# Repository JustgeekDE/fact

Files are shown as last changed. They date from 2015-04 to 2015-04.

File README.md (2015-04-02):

# Simple Fact
## Overview
Simple Fact (a simple **F**lash **a**nd **c**amera **t**rigger) is a smallish ([SoB 5x5](http://dangerousprototypes.com/docs/Sick_of_Beige_standard_PCB_sizes_v1.0)) tool to automatically trigger a a camera or camera flash based on sounds or light impulses.

The whole system is planned to be Arduino compatible to allow easy extension.

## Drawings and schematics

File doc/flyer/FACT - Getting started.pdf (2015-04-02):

## 1. 2. Connect in- and outputs Select the trigger mode

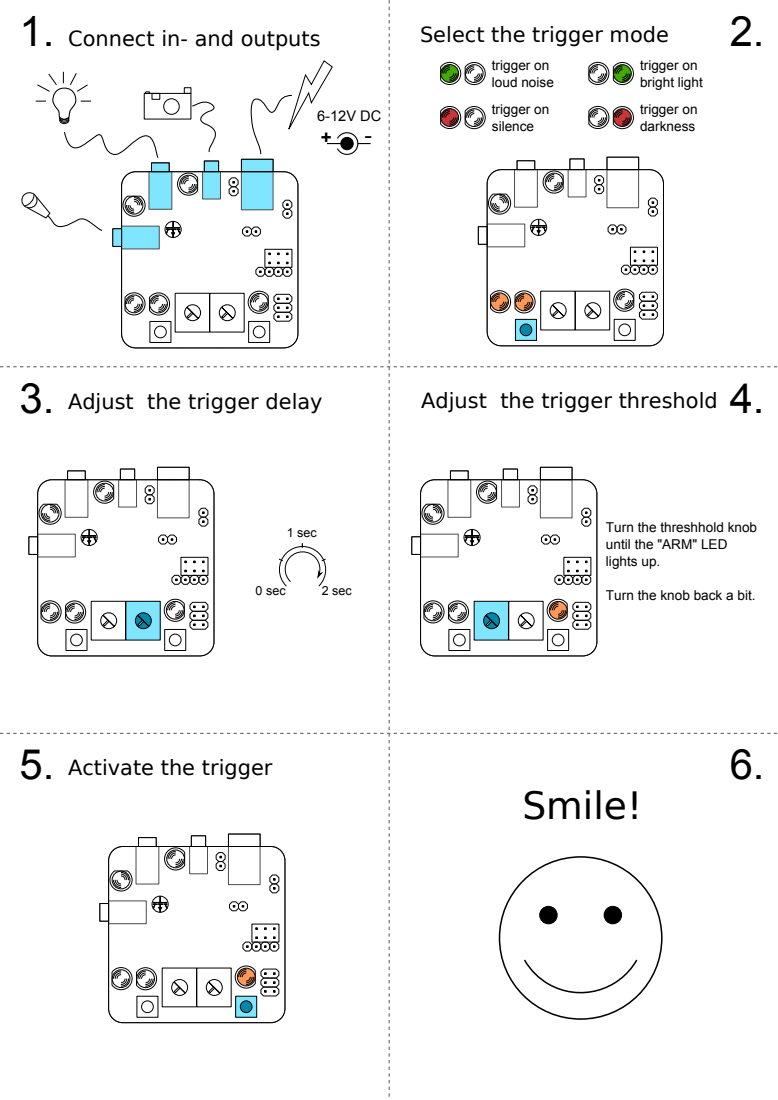
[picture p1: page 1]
trigger on loud noise; trigger on silence; trigger on bright light; trigger on darkness; 0 sec; 2 sec; 1 sec; Adjust the trigger delay; Adjust the trigger threshold; Smile!

Turn the threshhold knob
until the "ARM" LED
lights up.

Turn the knob back a bit.

Activate the trigger

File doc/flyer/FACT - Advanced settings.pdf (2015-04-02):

Connect a battery directly data to PC | data from PC | reset

## Load your own program

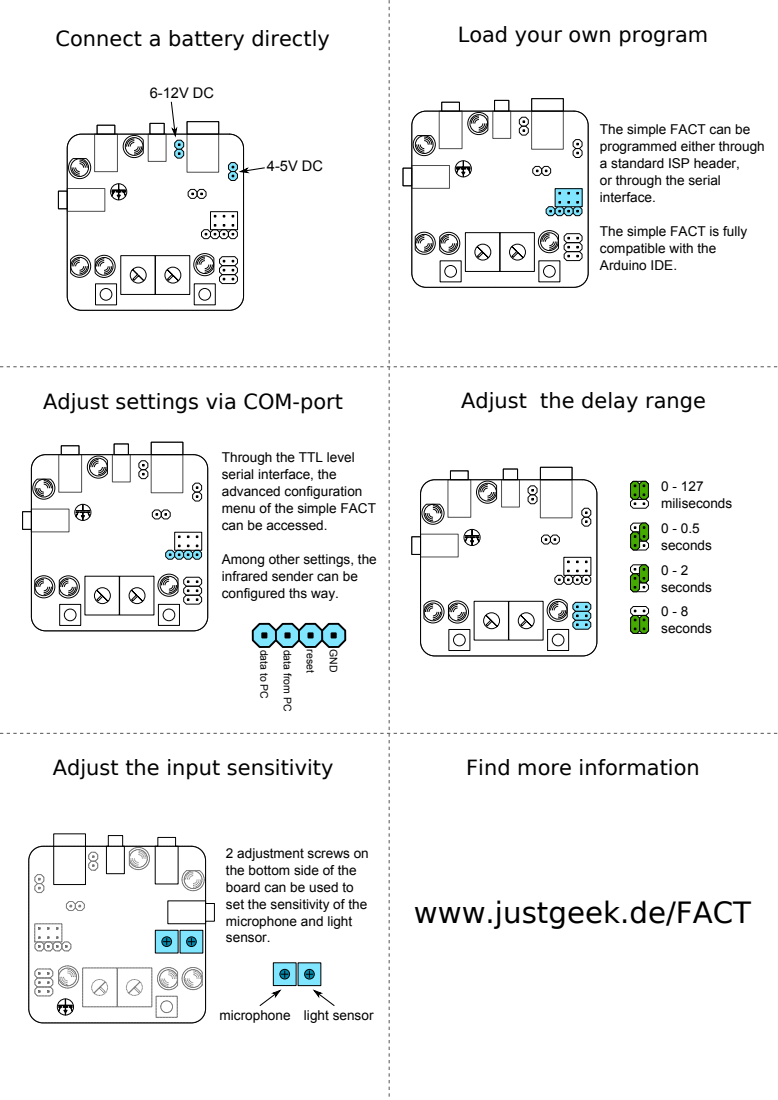
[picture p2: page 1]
GND; Adjust settings via COM-port; Adjust the delay range; 0 - 127 miliseconds; 0 - 0.5 seconds; 0 - 2 seconds; 0 - 8 seconds

The simple FACT can be
programmed either through
a standard ISP header,
or through the serial
interface.

The simple FACT is fully
compatible with the
Arduino IDE.

Through the TTL level
serial interface, the
advanced configuration
menu of the simple FACT
can be accessed.

Among other settings, the
infrared sender can be
configured ths way.

Adjust the input sensitivity

Find more information

2 adjustment screws on
the bottom side of the
board can be used to
set the sensitivity of the
microphone and light
sensor.

www.justgeek.de/FACT

microphone light sensor

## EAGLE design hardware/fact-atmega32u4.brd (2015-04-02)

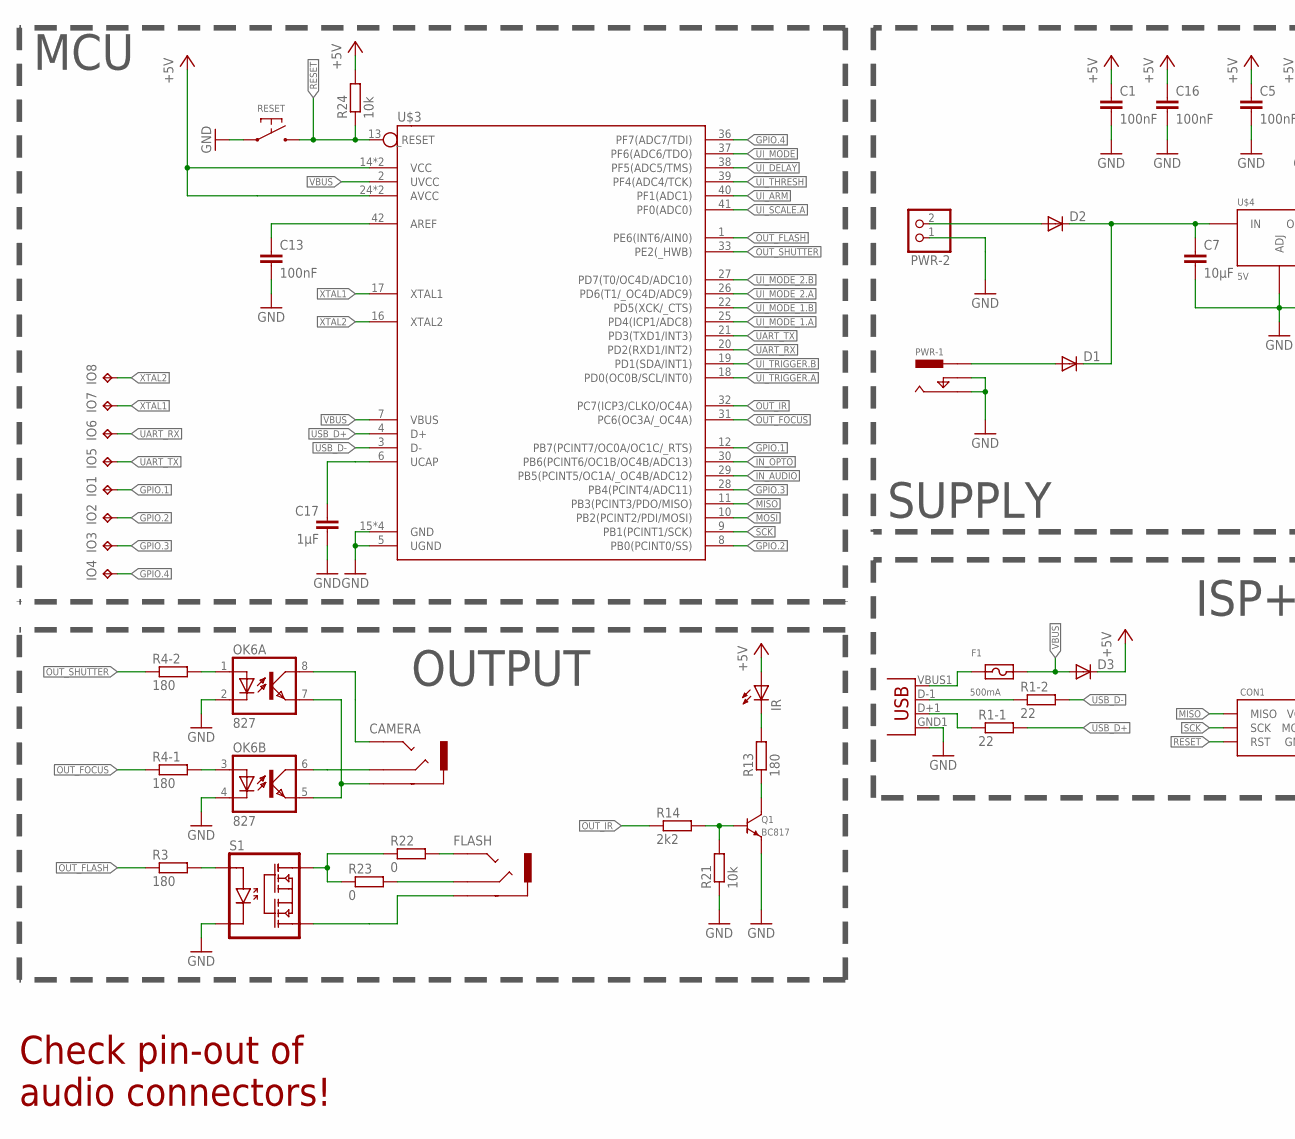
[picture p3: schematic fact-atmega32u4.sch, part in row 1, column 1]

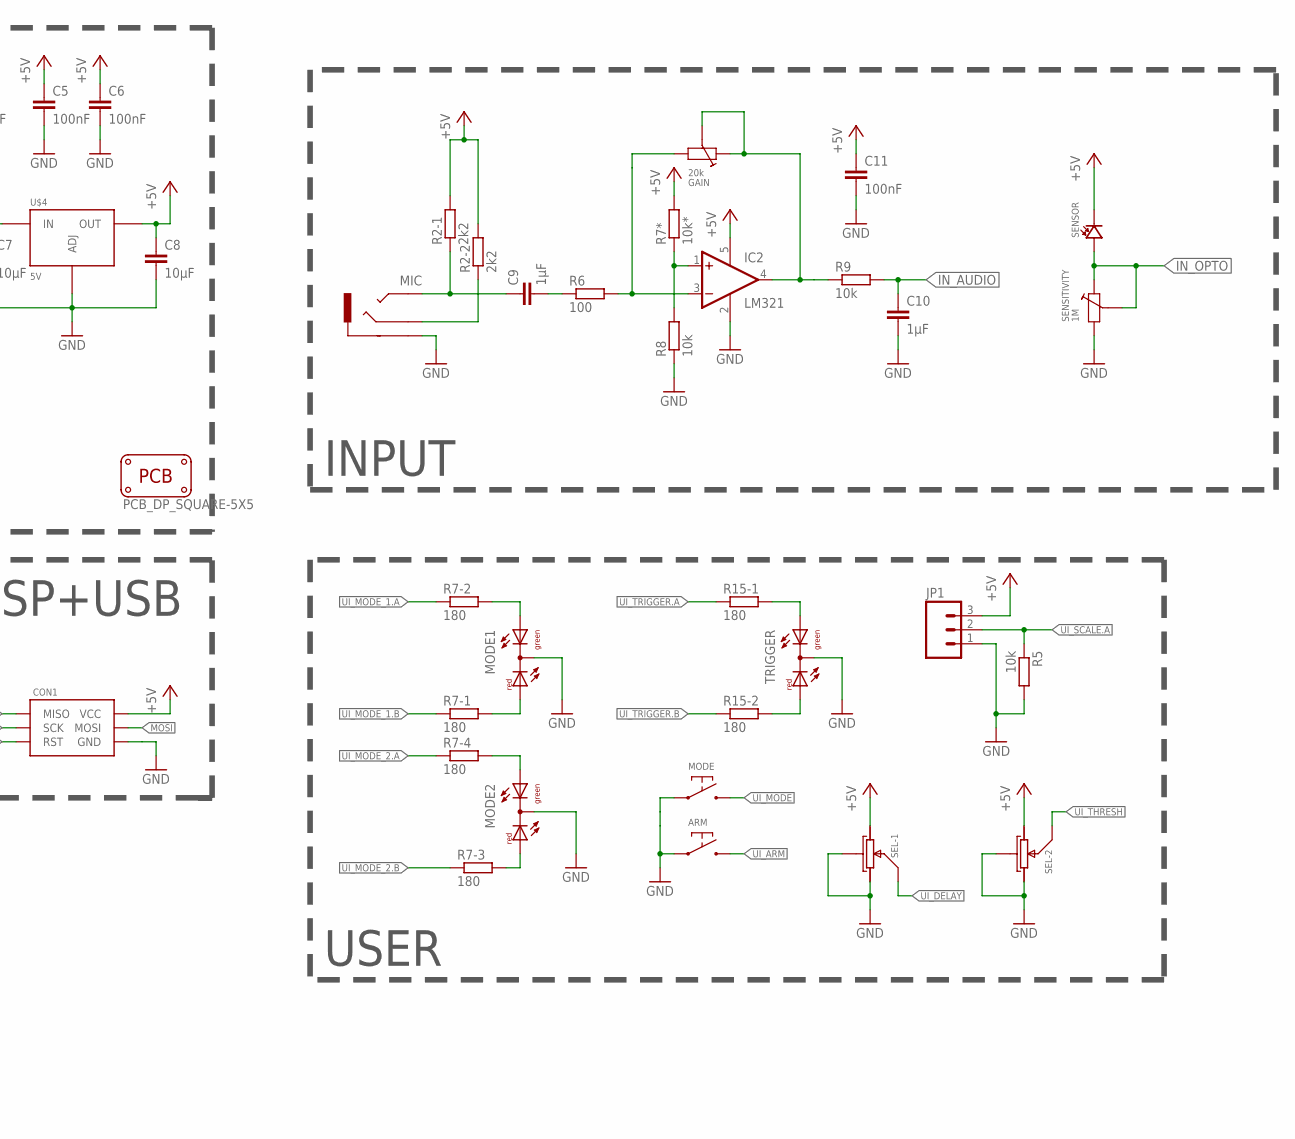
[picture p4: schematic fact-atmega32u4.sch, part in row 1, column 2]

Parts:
ARM: SWITCH-DEFAULT_OFF-DEFAULT; SWITCH-GENERIC-4_PIN
C1, C5, C6, C11, C13, C16: 100nF; C0603
C7, C8: 10µF; C0603
C9, C10, C17: 1µF; C0603
CAMERA: AUDIO-STEREO2MM5; AUDIO-STEREO-2MM5-SJ1-2503A
CON1: ISP-6_PIN-POGO; POGO-1.27-6_PIN-MADWORM
D1, D2, D3: DIODESOD; SOD-323
F1: 500mA; SMD-0805
FLASH: AUDIO-STEREODEALEXTREME; AUDIO-STEREO-3MM5-ST-009
GAIN: 20k; TRIM-POT-CA6-VS5
IC2: LM321; SOT23-5
IO1, IO2, IO3, IO4, IO5, IO6, IO7, IO8: TPTP15R; TP15R
IR: LED5MM
JP1: M03LOCK; 1X03_LOCK
MIC: AUDIO-STEREODEALEXTREME; AUDIO-STEREO-3MM5-ST-009
MODE: SWITCH-DEFAULT_OFF-DEFAULT; SWITCH-GENERIC-4_PIN
MODE1, MODE2: DUOLED-RG-C; DUOLED-C-5MM
OK6: 827; SMD08
PCB1: PCB_DP_SQUARE-5X5; DP5050_V1
PWR-1: POWER-BARREL_JACKEBAY; POWER-BARREL-2MM1-EBAY
PWR-2: PINHD-1X2; 1X02
Q1: BC817; SOT23
R1: 22; R-ARRAY-2X-0603
R2: 2k2; R-ARRAY-2X-0603
R3, R13: 180; R0603
R4, R15: 180; R-ARRAY-2X-0603
R5, R8, R9, R21, R24: 10k; R0603
R6: 100; R0603
R7: 180; R-ARRAY-4X-CTS-0603
R7*: 10k*; R0603
R14: 2k2; R0603
R22, R23: 0; R1206
RESET: SWITCH-DEFAULT_OFF-SMD-2_PIN; SWITCH-SMD-2_PIN-DX
S1: RELAYLH1500; SMD-06
SEL: DUAL-POT; POT-DUAL-P090
SENSITIVITY: 1M; TRIM-POT-CA6-VS5
SENSOR: PHOTODIODE; LED-5MM
TRIGGER: DUOLED-RG-C; DUOLED-C-5MM
U$3: ATMEGA32U4-QFN-HAND; QFN-44-NOPAD-LONGLEADS
U$4: 5V; SOT223
U$5: USB; USB-AB-MICRO-SMD_V03

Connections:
+5V: C1.1, C5.1, C6.1, C8.1, C11.1, C16.1, CON1.P$2 (VCC), D3.1 (C), IC2.5 (V+), IR.A, JP1.3, R2.P$1.2 (2), R2.P$2.2 (2), R7*.2, R24.2, SEL.P1-3 (B), SEL.P2-1 (A), SENSOR.K (C), U$3.14 (VCC), U$3.24 (AVCC), U$3.34 (VCC), U$3.44 (AVCC), U$4.2 (OUT), U$4.4 (OUT)
GND: ARM.P$1, ARM.P$2, C1.2, C5.2, C6.2, C7.2, C8.2, C10.2, C11.2, C13.2, C16.2, C17.2, CON1.P$6 (GND), IC2.2 (V-), JP1.1, MIC.P$1.1 (SLEEVE), MIC.P$1.2 (SLEEVE), MODE.P$1, MODE.P$2, MODE1.C, MODE2.C, OK6.2 (C), OK6.4 (C), PWR-1.P$2 (SWITCH), PWR-1.P$3 (OUTER), PWR-2.1, Q1.P$2 (EMITTER), R5.2, R8.1, R21.1, RESET.P$1, S1.2 (LED-C), SEL.CENTER (SHIELD), SEL.G1-S (SHIELD), SEL.G2-S (SHIELD), SEL.P1-1 (A), SEL.P2-3 (B), SENSITIVITY.P$2, TRIGGER.C, U$3.5 (UGND), U$3.15 (GND), U$3.23 (GND), U$3.35 (GND), U$3.43 (GND), U$4.1 (ADJ), U$5.GND1 (GND)
GPIO.1: IO1.TP, U$3.12 (PB7(PCINT7/OC0A/OC1C/_RTS))
GPIO.2: IO2.TP, U$3.8 (PB0(PCINT0/SS))
GPIO.3: IO3.TP, U$3.28 (PB4(PCINT4/ADC11))
GPIO.4: IO4.TP, U$3.36 (PF7(ADC7/TDI))
HV_OUT: R22.1, R23.1, S1.6 (R1)
HV_RING: FLASH.P$2 (RING), R23.2
HV_SLEEVE: FLASH.P$1.1 (SLEEVE), FLASH.P$1.2 (SLEEVE), S1.4 (R2)
HV_TIP: FLASH.P$3.1 (TIP), FLASH.P$3.2 (TIP), R22.2
IN_AUDIO: C10.1, R9.2, U$3.29 (PB5(PCINT5/OC1A/_OC4B/ADC12))
IN_OPTO: SENSITIVITY.CENTER, SENSITIVITY.P$1, SENSOR.A, U$3.30 (PB6(PCINT6/OC1B/OC4B/ADC13))
MISO: CON1.P$1 (MISO), U$3.11 (PB3(PCINT3/PDO/MISO))
MOSI: CON1.P$4 (MOSI), U$3.10 (PB2(PCINT2/PDI/MOSI))
unnamed: C7.1, D1.1 (C), D2.1 (C), U$4.3 (IN)
unnamed: F1.1, U$5.VBUS1 (VBUS)
unnamed: R1.P$2.1 (1), U$5.D-1 (D-)
unnamed: D1.2 (A), PWR-1.P$4 (CENTER)
unnamed: R1.P$1.1 (1), U$5.D+1 (D+)
unnamed: D2.2 (A), PWR-2.2
unnamed: CAMERA.P$1 (SLEEVE), OK6.5 (EMIT), OK6.7 (EMIT)
unnamed: CAMERA.P$4 (RING), OK6.6 (COL)
unnamed: CAMERA.P$2 (TIP), CAMERA.P$3 (TIP), OK6.8 (COL)
unnamed: OK6.1 (A), R4.P$2.2 (2)
unnamed: MIC.P$2 (RING), R2.P$2.1 (1)
unnamed: C9.1, MIC.P$3.1 (TIP), MIC.P$3.2 (TIP), R2.P$1.1 (1)
unnamed: IC2.1 (+IN), R7*.1, R8.2
unnamed: C9.2, R6.1
unnamed: GAIN.P$2, IC2.3 (-IN), R6.2
unnamed: GAIN.CENTER, GAIN.P$1, IC2.4 (OUT), R9.1
unnamed: R3.2, S1.1 (LED-A)
unnamed: OK6.3 (A), R4.P$1.2 (2)
unnamed: Q1.P$3 (COLLECTOR), R13.1
unnamed: IR.K (C), R13.2
unnamed: Q1.P$1 (BASE), R14.2, R21.2
unnamed: MODE1.AX (AG), R7.P$2.2 (2)
unnamed: MODE1.AR, R7.P$1.2 (2)
unnamed: R15.P$1.2 (2), TRIGGER.AX (AG)
unnamed: R15.P$2.2 (2), TRIGGER.AR
unnamed: MODE2.AX (AG), R7.P$4.2 (2)
unnamed: MODE2.AR, R7.P$3.2 (2)
unnamed: C13.1, U$3.42 (AREF)
unnamed: C17.1, U$3.6 (UCAP)
OUT_FLASH: R3.1, U$3.1 (PE6(INT6/AIN0))
OUT_FOCUS: R4.P$1.1 (1), U$3.31 (PC6(OC3A/_OC4A))
OUT_IR: R14.1, U$3.32 (PC7(ICP3/CLKO/OC4A))
OUT_SHUTTER: R4.P$2.1 (1), U$3.33 (PE2(_HWB))
RESET: CON1.P$5 (RST), R24.1, RESET.P$2, U$3.13 (_RESET)
SCK: CON1.P$3 (SCK), U$3.9 (PB1(PCINT1/SCK))
UART_RX: IO6.TP, U$3.20 (PD2(RXD1/INT2))
UART_TX: IO5.TP, U$3.21 (PD3(TXD1/INT3))
UI_ARM: ARM.P$3, ARM.P$4, U$3.40 (PF1(ADC1))
UI_DELAY: SEL.P1-2 (M), U$3.38 (PF5(ADC5/TMS))
UI_MODE: MODE.P$3, MODE.P$4, U$3.37 (PF6(ADC6/TDO))
UI_MODE_1.A: R7.P$2.1 (1), U$3.25 (PD4(ICP1/ADC8))
UI_MODE_1.B: R7.P$1.1 (1), U$3.22 (PD5(XCK/_CTS))
UI_MODE_2.A: R7.P$4.1 (1), U$3.26 (PD6(T1/_OC4D/ADC9))
UI_MODE_2.B: R7.P$3.1 (1), U$3.27 (PD7(T0/OC4D/ADC10))
UI_SCALE.A: JP1.2, R5.1, U$3.41 (PF0(ADC0))
UI_THRESH: SEL.P2-2 (M), U$3.39 (PF4(ADC4/TCK))
UI_TRIGGER.A: R15.P$1.1 (1), U$3.18 (PD0(OC0B/SCL/INT0))
UI_TRIGGER.B: R15.P$2.1 (1), U$3.19 (PD1(SDA/INT1))
USB_D+: R1.P$1.2 (2), U$3.4 (D+)
USB_D-: R1.P$2.2 (2), U$3.3 (D-)
VBUS: D3.2 (A), F1.2, U$3.2 (UVCC), U$3.7 (VBUS)
XTAL1: IO7.TP, U$3.17 (XTAL1)
XTAL2: IO8.TP, U$3.16 (XTAL2)

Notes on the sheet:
INPUT
OUTPUT
USER
SUPPLY
MCU
Check pin-out of audio connectors!
ISP+USB

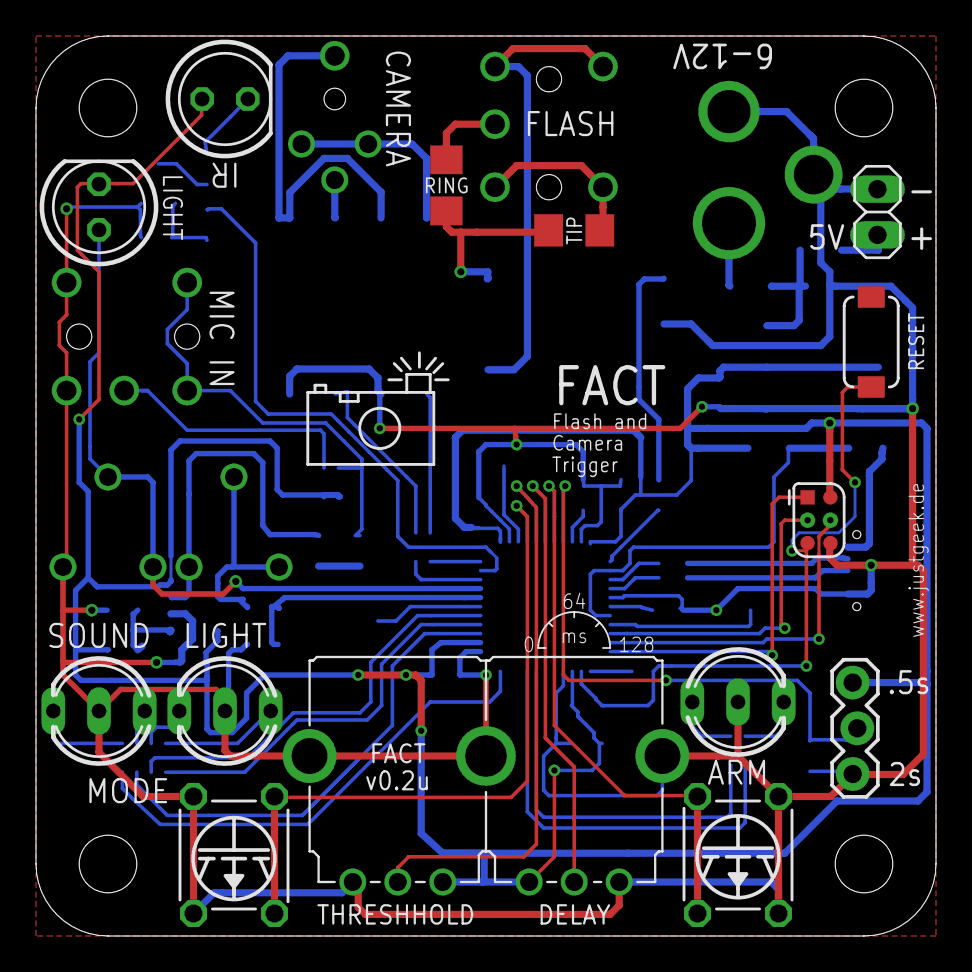
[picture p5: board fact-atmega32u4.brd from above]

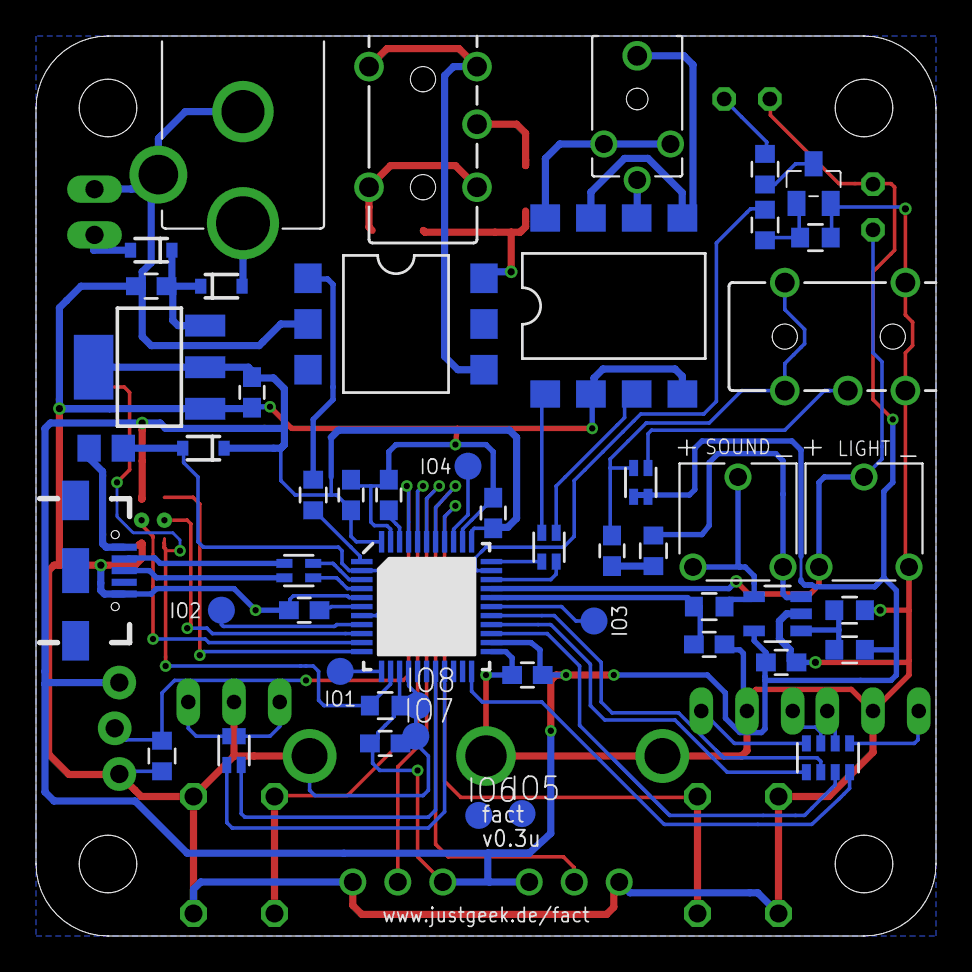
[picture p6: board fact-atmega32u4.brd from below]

Board: 2 copper layers, 50.0 x 50.0 mm, 70 parts (52 on the bottom side), 67 nets.

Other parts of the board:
U$1, U$2: LOGO-JUSTGEEK-XS
U$6, U$7: LOGO-JUSTGEEK-XXXS-MASK

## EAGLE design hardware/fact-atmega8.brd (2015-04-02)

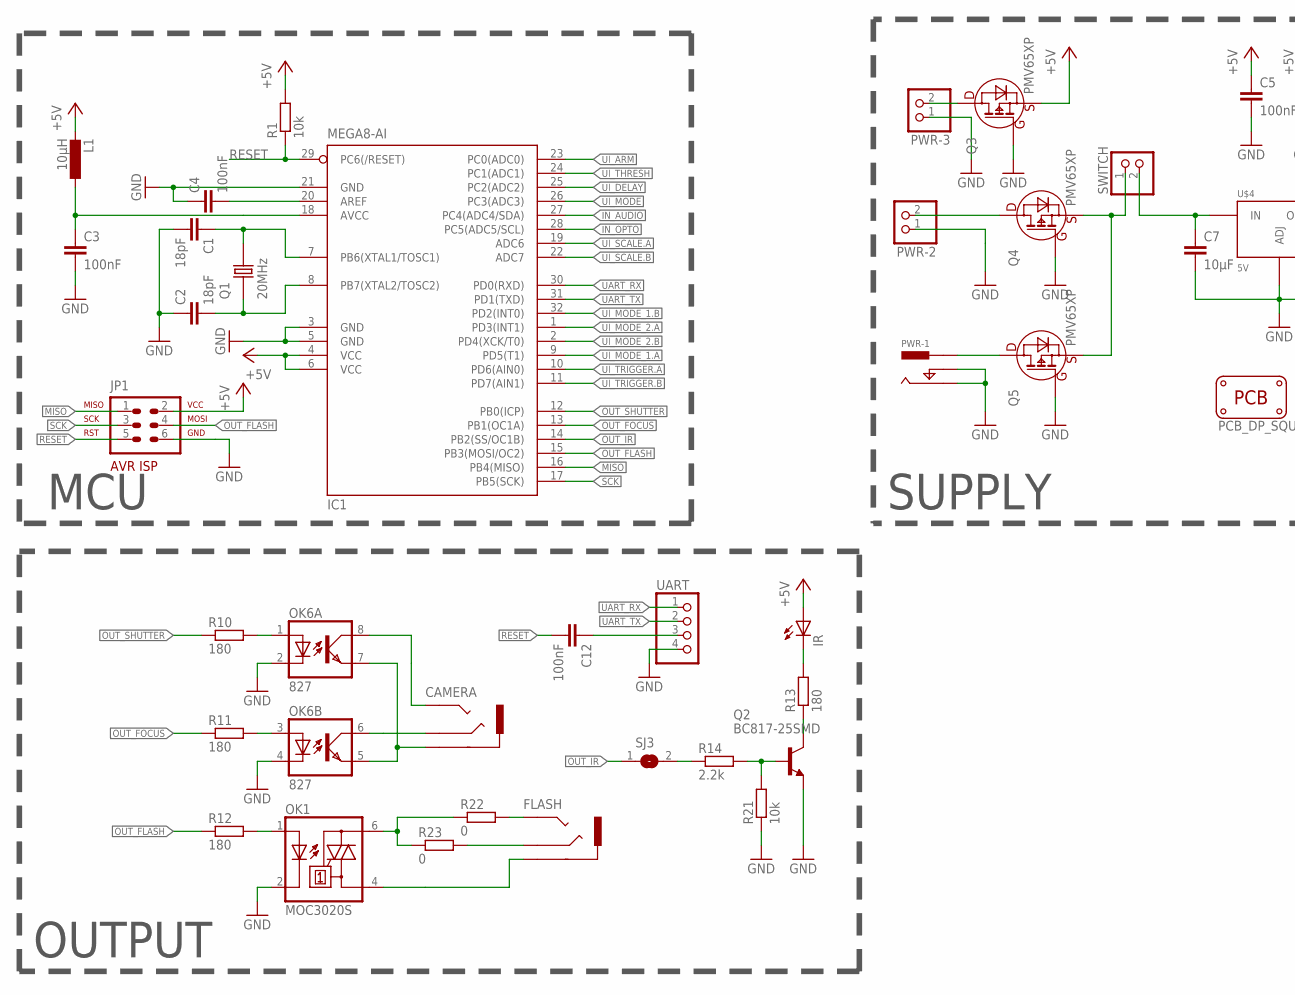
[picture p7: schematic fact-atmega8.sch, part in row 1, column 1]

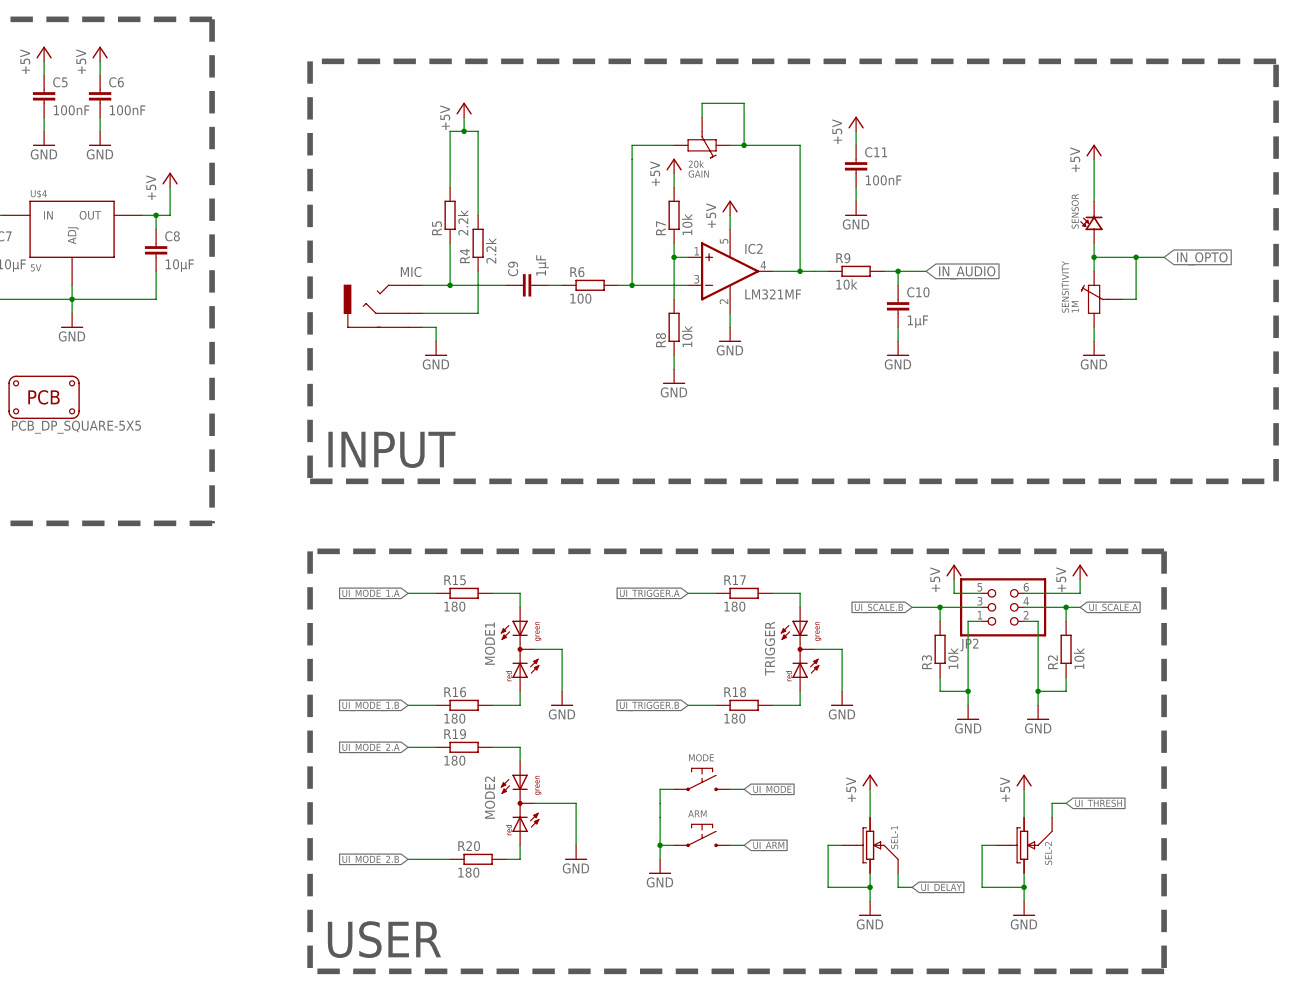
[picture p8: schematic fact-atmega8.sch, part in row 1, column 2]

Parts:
ARM: SWITCH-DEFAULT_OFF; SWITCH-GENERIC-4_PIN
C1, C2: 18pF; C0603
C3, C4, C5, C6, C11, C12: 100nF; C0603
C7, C8: 10µF; C0603
C9, C10: 1µF; C0603
CAMERA: AUDIO-STEREO2MM5; AUDIO-STEREO-2MM5-SJ1-2503A
FLASH: AUDIO-STEREOCONRAD; AUDIO-STEREO-CONRAD-KB3-3_PIN
GAIN: 20k; TRIM-POT-CA6-VS5
IC1: MEGA8-AI; TQFP32-08
IC2: LM321MF; SOT23-5
IR: LED5MM
JP1: AVR-ISP-6VERT; AVR-ISP-6
JP2: PINHD-2X3; 2X03
L1: 10µH; R0805
MIC: AUDIO-STEREOCONRAD-KB3; AUDIO-STEREO-CONRAD-KB3-3_PIN
MODE: SWITCH-DEFAULT_OFF; SWITCH-GENERIC-4_PIN
MODE1, MODE2: DUOLED-RG-C; DUOLED-C-5MM
OK1: MOC3020S; DIL6-SMD
OK6: 827; SMD08
PCB1: PCB_DP_SQUARE-5X5; DP5050_V1
PWR-1: POWER-BARREL_JACKPJ-102A; POWER-BARREL-2MM1-PJ_102A
PWR-2, PWR-3: PINHD-1X2; 1X02
Q1: 20MHz; CRYSTAL-SMD-5MM_X_3.2MM
Q2: BC817-25SMD; SOT23-BEC
Q3, Q4, Q5: PMV65XP; SOT23
R1, R2, R3, R7, R8, R9, R21: 10k; R0603
R4, R5, R14: 2.2k; R0603
R6: 100; R0603
R10, R11, R12, R13, R15, R16, R17, R18, R19, R20: 180; R0603
R22, R23: 0; R1206
SEL: DUAL-POT; POT-DUAL-P090
SENSITIVITY: 1M; TRIM-POT-CA6-VS5
SENSOR: PHOTODIODE; LED-5MM
SJ3: SJ
SWITCH: PINHD-1X2; 1X02
TRIGGER: DUOLED-RG-C; DUOLED-C-5MM
U$4: 5V; SOT223
UART: PINHD-1X4; 1X04

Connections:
+5V: C5.1, C6.1, C8.1, C11.1, IC1.4 (VCC), IC1.6 (VCC), IC2.5 (V+), IR.A, JP1.2, JP2.5, JP2.6, L1.2, Q3.P$2 (SOURCE), R1.2, R4.2, R5.2, R7.2, SEL.P1-3 (B), SEL.P2-1 (A), SENSOR.K (C), U$4.2 (OUT)
GND: ARM.P$1, ARM.P$2, C1.2, C2.1, C3.2, C4.1, C5.2, C6.2, C7.2, C8.2, C10.2, C11.2, IC1.3 (GND), IC1.5 (GND), IC1.21 (GND), IC2.2 (V-), JP1.6, JP2.1, JP2.2, MIC.2.1 (SLEEVE), MIC.2.2 (SLEEVE), MODE.P$1, MODE.P$2, MODE1.C, MODE2.C, OK1.2 (C), OK6.2 (C), OK6.4 (C), PWR-1.P$2 (OUTER), PWR-1.P$3 (SWITCH), PWR-2.1, PWR-3.1, Q2.E, Q3.P$1 (GATE), Q4.P$1 (GATE), Q5.P$1 (GATE), R2.1, R3.1, R8.1, R21.1, SEL.CENTER (SHIELD), SEL.G1-S (SHIELD), SEL.G2-S (SHIELD), SEL.P1-1 (A), SEL.P2-3 (B), SENSITIVITY.P$2, TRIGGER.C, U$4.1 (ADJ), U$4.4 (ADJ), UART.4
HV_OUT: OK1.6 (A2), R22.1, R23.1
HV_RING: FLASH.2.1 (RING), FLASH.2.2 (RING), R23.2
HV_SLEEVE: FLASH.1 (SLEEVE), OK1.4 (A1)
HV_TIP: FLASH.3 (TIP), R22.2
IN_AUDIO: C10.1, IC1.27 (PC4(ADC4/SDA)), R9.2
IN_OPTO: IC1.28 (PC5(ADC5/SCL)), SENSITIVITY.CENTER, SENSITIVITY.P$1, SENSOR.A
MISO: IC1.16 (PB4(MISO)), JP1.1
unnamed: R14.1, SJ3.2
unnamed: C7.1, SWITCH.2, U$4.3 (IN)
unnamed: C3.1, IC1.18 (AVCC), L1.1
unnamed: C4.2, IC1.20 (AREF)
unnamed: PWR-1.P$1 (CENTER), Q5.P$3 (DRAIN)
unnamed: C1.1, IC1.7 (PB6(XTAL1/TOSC1)), Q1.P$2 (C2)
unnamed: C2.2, IC1.8 (PB7(XTAL2/TOSC2)), Q1.P$1 (C1)
unnamed: PWR-2.2, Q4.P$3 (DRAIN)
unnamed: Q4.P$2 (SOURCE), Q5.P$2 (SOURCE), SWITCH.1
unnamed: PWR-3.2, Q3.P$3 (DRAIN)
unnamed: CAMERA.P$1 (SLEEVE), OK6.5 (EMIT), OK6.7 (EMIT)
unnamed: CAMERA.P$4 (RING), OK6.6 (COL)
unnamed: CAMERA.P$2 (TIP), CAMERA.P$3 (TIP), OK6.8 (COL)
unnamed: OK6.1 (A), R10.2
unnamed: MIC.1 (RING), R4.1
unnamed: C9.1, MIC.3 (TIP), R5.1
unnamed: IC2.1 (+IN), R7.1, R8.2
unnamed: C9.2, R6.1
unnamed: GAIN.P$2, IC2.3 (-IN), R6.2
unnamed: GAIN.CENTER, GAIN.P$1, IC2.4 (OUT), R9.1
unnamed: OK1.1 (A), R12.2
unnamed: OK6.3 (A), R11.2
unnamed: Q2.C, R13.1
unnamed: IR.K (C), R13.2
unnamed: Q2.B, R14.2, R21.2
unnamed: MODE1.AX (AG), R15.2
unnamed: MODE1.AR, R16.2
unnamed: R17.2, TRIGGER.AX (AG)
unnamed: R18.2, TRIGGER.AR
unnamed: C12.1, UART.3
unnamed: MODE2.AX (AG), R19.2
unnamed: MODE2.AR, R20.2
OUT_FLASH: IC1.15 (PB3(MOSI/OC2)), JP1.4, R12.1
OUT_FOCUS: IC1.13 (PB1(OC1A)), R11.1
OUT_IR: IC1.14 (PB2(SS/OC1B)), SJ3.1
OUT_SHUTTER: IC1.12 (PB0(ICP)), R10.1
RESET: C12.2, IC1.29 (PC6(/RESET)), JP1.5, R1.1
SCK: IC1.17 (PB5(SCK)), JP1.3
UART_RX: IC1.30 (PD0(RXD)), UART.1
UART_TX: IC1.31 (PD1(TXD)), UART.2
UI_ARM: ARM.P$3, ARM.P$4, IC1.23 (PC0(ADC0))
UI_DELAY: IC1.25 (PC2(ADC2)), SEL.P1-2 (M)
UI_MODE: IC1.26 (PC3(ADC3)), MODE.P$3, MODE.P$4
UI_MODE_1.A: IC1.9 (PD5(T1)), R15.1
UI_MODE_1.B: IC1.32 (PD2(INT0)), R16.1
UI_MODE_2.A: IC1.1 (PD3(INT1)), R19.1
UI_MODE_2.B: IC1.2 (PD4(XCK/T0)), R20.1
UI_SCALE.A: IC1.19 (ADC6), JP2.4, R2.2
UI_SCALE.B: IC1.22 (ADC7), JP2.3, R3.2
UI_THRESH: IC1.24 (PC1(ADC1)), SEL.P2-2 (M)
UI_TRIGGER.A: IC1.10 (PD6(AIN0)), R17.1
UI_TRIGGER.B: IC1.11 (PD7(AIN1)), R18.1

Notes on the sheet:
INPUT
OUTPUT
USER
SUPPLY
MCU

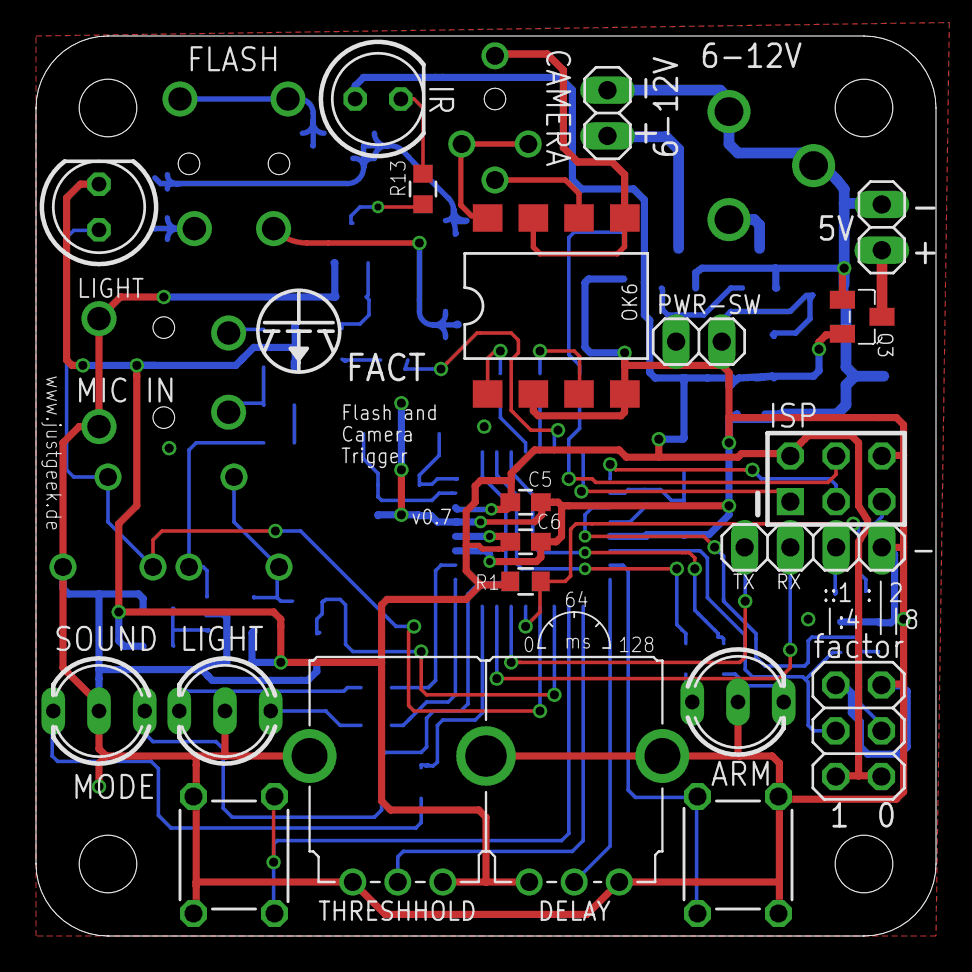
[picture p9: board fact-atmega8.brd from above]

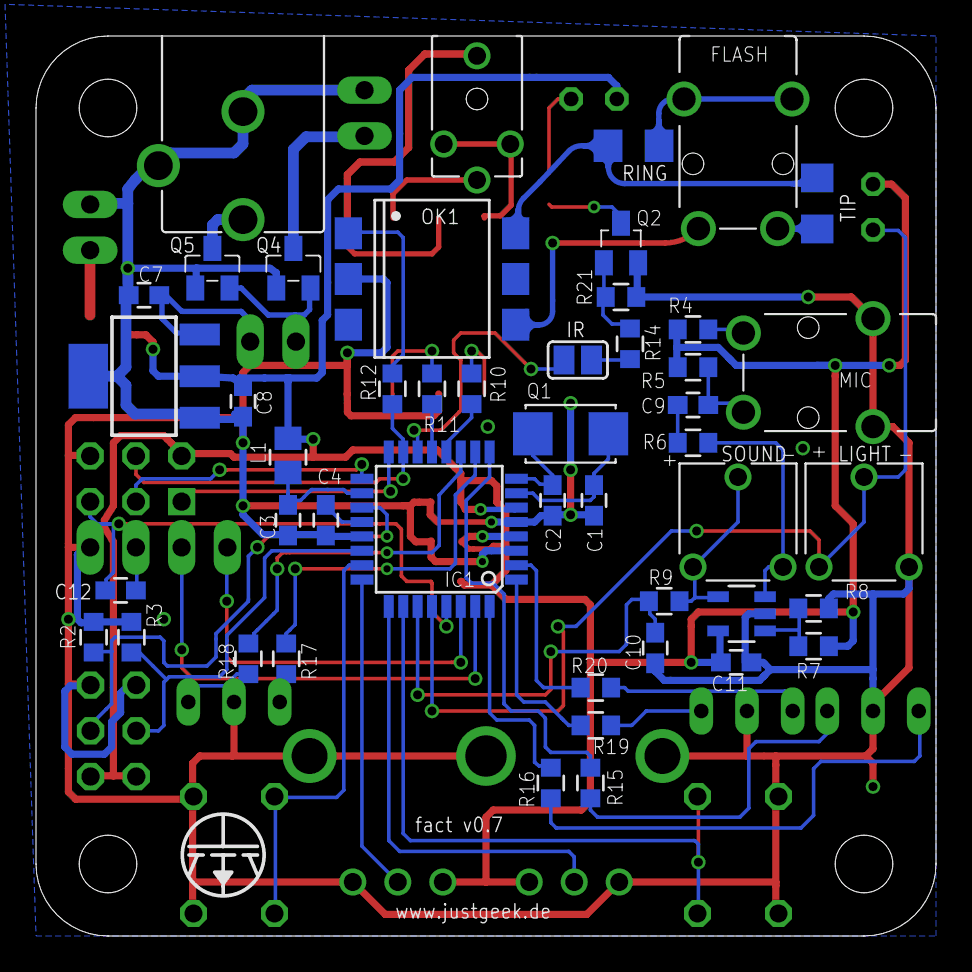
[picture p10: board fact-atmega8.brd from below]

Board: 2 copper layers, 50.0 x 50.0 mm, 70 parts (48 on the bottom side), 61 nets.

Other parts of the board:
U$1, U$2: LOGO-JUSTGEEK-XS

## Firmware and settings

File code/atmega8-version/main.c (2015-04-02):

#include <stdint.h>
#include <avr/interrupt.h>
#include <avr/wdt.h>

#include <stdlib.h>

#include "pins.h"
#include "uart.h"
#include "ui.h"
#include "time.h"
#include "sensor.h"
#include "trigger.h"

#define DEBUG 0
#define EXTENDED_MODES 1
#define TOTAL_MODES 8
#define LONG_PRESS_DURATION 750
#define UI_UPDATE_INTERVALL 50

inline uint8_t triggerDirectionFromMode(uint8_t mode){
	// first bit is direction;
	return (mode & 0x01) ? 1 : 0;
}

inline uint8_t sensorChannelFromMode(uint8_t mode){
	// second bit is channel;
	return ((mode & 0x02) ? SENSOR_LIGHT_CHANNEL : SENSOR_SOUND_CHANNEL);
}

inline uint8_t bulbSettingFromMode(uint8_t mode){
	// third bit is bulb;
	return ((mode & 0x04) ? 1 : 0);
}

void printDebug(uint8_t mode, uint8_t continousMode){
	char buffy[48];
	uint8_t triggerOnLow =  triggerDirectionFromMode(mode);
	uint8_t channel = sensorChannelFromMode(mode);
	uint8_t bulbMode = bulbSettingFromMode(mode);

	if(mode == 8){
		uart_puts("\n\rTriggering every ");
		utoa( ui_getDelay(), buffy, 10 );
		uart_puts(buffy);
		uart_puts(" seconds.");
	} else {
		char* channelString = (channel == SENSOR_SOUND_CHANNEL) ? "Sound" : ((channel == SENSOR_LIGHT_CHANNEL ? "light" : "invalid"));

		uart_puts("\n\rMonitoring: ");
		uart_puts(channelString);

		uart_puts("\n\rTriggering ");
		uart_puts((continousMode ? "continously" : "once"));

		uart_puts(" on ");
		uart_puts((triggerOnLow ? "low" : "high"));

		uart_puts("\n\rBulb mode is ");
		uart_puts((bulbMode ? "on" : "off"));

		uart_puts("\n\rThreshold: ");
		utoa( ui_getThreshold(), buffy, 10 );
		uart_puts(buffy);

		uart_puts("\t\tDelay: ");
		utoa( ui_getDelay(), buffy, 10 );
		uart_puts(buffy);

		uart_puts("\n\rCurrent value is: ");
		utoa( sensor_read(channel), buffy, 10 );
		uart_puts(buffy);
	}
}

int main(void) {
	wdt_disable();
	cli();
	trigger_setup();
	ui_setup();
	uart_setup();
	time_setup();
	sensor_setup();
	sei();


	uart_puts("\n\n\r***************************************");
	uart_puts("\n\r*                                     *");
	uart_puts("\n\r*  simple FACT, simple firmware v0.2  *");
	uart_puts("\n\r*                                     *");
	uart_puts("\n\r***************************************");

	char buffy[48];

	uint8_t mode = 0;
	uint8_t armed = 0;
	uint16_t threshold = 0;
	uint8_t armDecay = 0;

	uint8_t triggerOnLow =  triggerDirectionFromMode(mode);
	uint8_t channel = sensorChannelFromMode(mode);
	uint8_t bulbMode = bulbSettingFromMode(mode);
	uint8_t continousMode = 0;
	uint32_t delay = 0;

	uint32_t lastUIUpdate = 0;
	uint32_t armPressed = 0;
	uint32_t lastTrigger = 0;
	uint32_t triggerIntervall = 0;

	ui_setLedMode(mode, armed);

	while(1){
		if(armed){
			// check if we should abort
			if(ui_getButtonState(UI_BUTTON_ARM) == UI_BUTTON_DOWN){
				ui_setArmedLed(0, 1);
			}

			if(mode == 8){
				// intervall trigger
				if(time_getDifference(lastTrigger, time_getMS()) >= triggerIntervall){
					trigger_setTriggers(1,1,0);
					lastTrigger = time_getMS();
					time_delayMS(100);
					trigger_setTriggers(0,0,0);

					utoa( lastTrigger, buffy, 10 );
					uart_puts(buffy);
					uart_puts(", ");
				}
			} else {
				if(sensor_wasTriggered()){
					uart_puts("\n\r+++ Triggered with value: ");
					utoa( sensor_getTriggeredValue(), buffy, 10 );
					uart_puts(buffy);
					uart_puts(" +++\n");

					if(continousMode){
						if(bulbMode){
							time_delayMS(100);
						}
						uart_puts("\n\r\tRearming...");
						ui_setLedMode(mode, armed); // disable LEDs before setting triggers
						trigger_reset();
						sensor_resetTrigger();
					} else {
						armed = 0;
						trigger_setTriggers(0,0,0);
						ui_setLedMode(mode, armed);
					}
				}
			}

			if((ui_getButtonChange(UI_BUTTON_MODE) == UI_BUTTON_RELEASED) || (ui_getButtonChange(UI_BUTTON_ARM) == UI_BUTTON_RELEASED)){
				uart_puts("\n\r--- Aborted! ---\n");
				// abort
				armed = 0;
				sensor_abortTrigger();
				trigger_setTriggers(0,0,0);
				ui_setLedMode(mode, armed);
			}

		} else {
			// If not armed to various checks
			int8_t modeButtonChange = ui_getButtonChange(UI_BUTTON_MODE);
			int8_t armButtonChange = ui_getButtonChange(UI_BUTTON_ARM);
			int8_t modeButtonState = ui_getButtonState(UI_BUTTON_MODE);
			int8_t armButtonState = ui_getButtonState(UI_BUTTON_ARM);


			if(modeButtonChange == UI_BUTTON_RELEASED){
				mode++;
//				mode = mode & TOTAL_MODES;
				while(mode > TOTAL_MODES){
					mode -= TOTAL_MODES;
				}
				armDecay = 0;
				triggerOnLow =  triggerDirectionFromMode(mode);
				channel = sensorChannelFromMode(mode);
				bulbMode = bulbSettingFromMode(mode);

				uart_puts("\n");
				printDebug(mode, 0);
				lastUIUpdate = time_getMS();

			}
			
			if(armButtonChange == UI_BUTTON_PRESSED){
				ui_setArmedLed(1, 0);
				armPressed = time_getMS();
			}

			if(time_getDifference(lastUIUpdate, time_getMS()) > UI_UPDATE_INTERVALL){
				lastUIUpdate = time_getMS();
				threshold = ui_getThreshold();
				if(armDecay){
					armDecay--;
				}
			}

			uint16_t value = sensor_read(channel);
			if(triggerOnLow && (value < threshold)){
				armDecay = 5;
			}
			if(!triggerOnLow && (value > threshold)){
				armDecay = 5;
			}
			ui_setLedMode(mode, armed);

			if(armButtonState == UI_BUTTON_DOWN){
				if(time_getDifference(armPressed, time_getMS()) > LONG_PRESS_DURATION){
					ui_setArmedLed(1, 1);
				}
			} else {
				ui_setArmedLed(armDecay, 0);
			}



			if(armButtonChange == UI_BUTTON_RELEASED){
				armed = 1;
				if(time_getDifference(armPressed, time_getMS()) > LONG_PRESS_DURATION){
					continousMode = 1;
				} else {
					continousMode = 0;
				}

				delay = ui_getDelay();
				ui_setLedMode(mode, armed); // disable LEDs before setting triggers

				uart_puts("\n\n\r +++ Arming +++");
				printDebug(mode, continousMode);

				if(mode == 8){
					triggerIntervall = delay * 1000;
					lastTrigger = time_getMS();
				} else {
					trigger_set(1, 1, delay, bulbMode, 1);
					sensor_setTrigger(channel, threshold, triggerOnLow);
				}
			}
		}
	}
}

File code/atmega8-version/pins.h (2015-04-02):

#ifndef __PINS_H
#define __PINS_H


#define SET_BIT(port,bit)   (port |=  (1 << bit))
#define CLEAR_BIT(port,bit) (port &= ~(1 << bit))
#define READ_BIT(port,bit)  ((port & (1 << bit)) ? 1 : 0)



/* User interface Buttons */
#define UI_BUTTON_PORT PORTC
#define UI_BUTTON_DDR  DDRC
#define UI_BUTTON_PIN  PINC

#define UI_BUTTON_ARM_PORT PORTC
#define UI_BUTTON_ARM_DDR  DDRC
#define UI_BUTTON_ARM_PIN  PINC
#define UI_BUTTON_ARM_BIT  PC0

#define UI_BUTTON_MODE_PORT PORTC
#define UI_BUTTON_MODE_DDR  DDRC
#define UI_BUTTON_MODE_PIN  PINC
#define UI_BUTTON_MODE_BIT  PC3

/* User interface Knobs */
#define UI_POT_THRESH_PORT PORTC
#define UI_POT_THRESH_DDR  DDRC
#define UI_POT_THRESH_PIN  PINC
#define UI_POT_THRESH_BIT  PC1
#define UI_POT_THRESH_CHANNEL 2

#define UI_POT_DELAY_PORT PORTC
#define UI_POT_DELAY_DDR  DDRC
#define UI_POT_DELAY_PIN  PINC
#define UI_POT_DELAY_BIT  PC2
#define UI_POT_DELAY_CHANNEL 1

/* User interface Jumper */
#define UI_JUMPER_A_CHANNEL 6
#define UI_JUMPER_B_CHANNEL 7

/* User Interface LEDs */
#define UI_LED_PORT PORTD
#define UI_LED_DDR  DDRD
#define UI_LED_PIN  PIND

#define UI_LED_SOUND_GREEN_PORT PORTD
#define UI_LED_SOUND_GREEN_DDR  DDRD
#define UI_LED_SOUND_GREEN_PIN  PIND
#define UI_LED_SOUND_GREEN_BIT  PD2

#define UI_LED_SOUND_RED_PORT PORTD
#define UI_LED_SOUND_RED_DDR  DDRD
#define UI_LED_SOUND_RED_PIN  PIND
#define UI_LED_SOUND_RED_BIT  PD5

#define UI_LED_LIGHT_GREEN_PORT PORTD
#define UI_LED_LIGHT_GREEN_DDR  DDRD
#define UI_LED_LIGHT_GREEN_PIN  PIND
#define UI_LED_LIGHT_GREEN_BIT  PD4

#define UI_LED_LIGHT_RED_PORT PORTD
#define UI_LED_LIGHT_RED_DDR  DDRD
#define UI_LED_LIGHT_RED_PIN  PIND
#define UI_LED_LIGHT_RED_BIT  PD3

#define UI_LED_ARMED_GREEN_PORT PORTD
#define UI_LED_ARMED_GREEN_DDR  DDRD
#define UI_LED_ARMED_GREEN_PIN  PIND
#define UI_LED_ARMED_GREEN_BIT  PD6

#define UI_LED_ARMED_RED_PORT PORTD
#define UI_LED_ARMED_RED_DDR  DDRD
#define UI_LED_ARMED_RED_PIN  PIND
#define UI_LED_ARMED_RED_BIT  PD7

#define UI_LED_MODE_BITMASK ((1 << UI_LED_SOUND_GREEN_BIT) | (1 << UI_LED_SOUND_RED_BIT) | (1 << UI_LED_LIGHT_GREEN_BIT) | (1 << UI_LED_LIGHT_RED_BIT))
#define UI_LED_BITMASK (UI_LED_MODE_BITMASK | (1 << UI_LED_ARMED_GREEN_BIT) | (1 << UI_LED_ARMED_RED_BIT))

/* Data input */
#define SENSOR_SOUND_PORT    PORTC
#define SENSOR_SOUND_DDR     DDRC
#define SENSOR_SOUND_PIN     PINC
#define SENSOR_SOUND_BIT     PC4
#define SENSOR_SOUND_CHANNEL 4

#define SENSOR_LIGHT_PORT    PORTC
#define SENSOR_LIGHT_DDR     DDRC
#define SENSOR_LIGHT_PIN     PINC
#define SENSOR_LIGHT_BIT     PC5
#define SENSOR_LIGHT_CHANNEL 5

/* Trigger outputs */
#define TRIGGER_PORT PORTB
#define TRIGGER_DDR  DDRB
#define TRIGGER_PIN  PINB

#define TRIGGER_SHUTTER_PORT PORTB
#define TRIGGER_SHUTTER_DDR  DDRB
#define TRIGGER_SHUTTER_PIN  PINB
#define TRIGGER_SHUTTER_BIT  PB0

#define TRIGGER_FOCUS_PORT PORTB
#define TRIGGER_FOCUS_DDR  DDRB
#define TRIGGER_FOCUS_PIN  PINB
#define TRIGGER_FOCUS_BIT  PB1

#define TRIGGER_FLASH_PORT PORTB
#define TRIGGER_FLASH_DDR  DDRB
#define TRIGGER_FLASH_PIN  PINB
#define TRIGGER_FLASH_BIT  PB3

#define TRIGGER_IR_PORT PORTB
#define TRIGGER_IR_DDR  DDRB
#define TRIGGER_IR_PIN  PINB
#define TRIGGER_IR_BIT  PB2


#endif

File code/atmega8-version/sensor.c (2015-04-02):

#include <stdint.h>
#include <avr/io.h>
#include <avr/interrupt.h>

#include "sensor.h"
#include "pins.h"
#include "trigger.h"

volatile uint8_t sensor_freeRunning = 0;
uint8_t sensor_triggerOnLow = 0;
uint16_t sensor_threshold = 0;
uint8_t sensor_channel = 0;

volatile uint16_t sensor_triggeredValue = 0;

#define SENSOR_ADC_START() (ADCSRA |= (1 << ADSC))

inline void sensor_selectChannel(uint8_t channel){
  // wait for current read to end
  while (ADCSRA & (1<<ADSC));
  // Select channel
  ADMUX = (ADMUX & ~(0x0F)) | (channel & 0x0F);
}

inline void sensor_setIRQ(uint8_t enable){
  if(enable){
    ADCSRA |= (1 << ADIE) | (1 << ADATE); 
  } else {
    ADCSRA &= ~((1 << ADIE) | (1 << ADATE)); 
  }
}


ISR(ADC_vect){
  uint16_t result = ADCW;
  if(((result < sensor_threshold) && (sensor_triggerOnLow != 0)) || ((result > sensor_threshold) && (sensor_triggerOnLow == 0))) {
    sensor_setIRQ(0);
    trigger_trigger();
    sensor_triggeredValue = result;
    sensor_freeRunning = 0;
  }
}

uint8_t sensor_setup(void){
  // enable with prescaler 128
  ADCSRA |= (1 << ADEN) | (1 << ADPS2) | (1 << ADPS1) | (1 << ADPS0);
  // enable with prescaler 64
//  ADCSRA |= (1 << ADEN) | (1 << ADPS2) | (1 << ADPS1) | (0 << ADPS0);

  // AV ref
  ADMUX = (1 << REFS0);


  return 1;
}

void sensor_setTrigger(uint8_t channel, uint16_t threshold, uint8_t triggerOnLow){
  sensor_threshold = threshold;
  sensor_triggerOnLow = triggerOnLow;
  sensor_channel = channel;
  sensor_resetTrigger();
}

void sensor_resetTrigger(void){
  sensor_triggeredValue = 0;

  // read twice, just to make sure it is clean
  sensor_read(sensor_channel);
  sensor_read(sensor_channel);
  sensor_freeRunning = 1;
  sensor_selectChannel(sensor_channel);
  sensor_setIRQ(1);
  SENSOR_ADC_START();
}

void sensor_abortTrigger(void){
  sensor_setIRQ(0);
  while (ADCSRA & (1<<ADSC) );
  sensor_freeRunning = 0;
}

uint16_t sensor_read(uint8_t channel){
  if(sensor_freeRunning){
    return 0;
  }
  sensor_selectChannel(channel);
  SENSOR_ADC_START();
  while (ADCSRA & (1<<ADSC) );
  return ADCW;
}

uint8_t sensor_wasTriggered(void){
  return (!sensor_freeRunning);
}

uint16_t sensor_getTriggeredValue(void){
  return sensor_triggeredValue;
}

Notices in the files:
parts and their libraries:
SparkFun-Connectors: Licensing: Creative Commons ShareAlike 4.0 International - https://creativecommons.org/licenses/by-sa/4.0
